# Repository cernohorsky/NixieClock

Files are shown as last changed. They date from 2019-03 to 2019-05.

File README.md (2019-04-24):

# NixieClock Arduino Mega shield
NixieClock PCB for nixie tubes ZM1080, ZM1082, Z570M, Z5700M. High voltage DC-DC convertor. RTC for time synchronization.

<b>Ideas:</b><br>
Different DCDC convertor parts values<br>
Different buttons position<br>

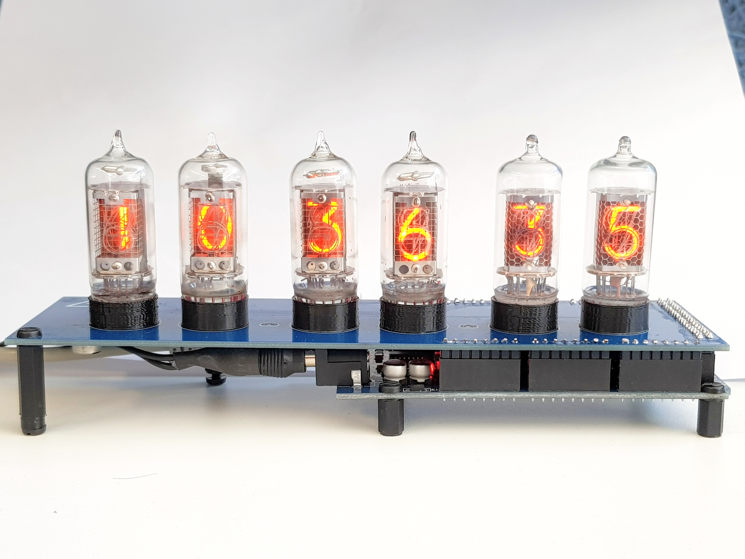
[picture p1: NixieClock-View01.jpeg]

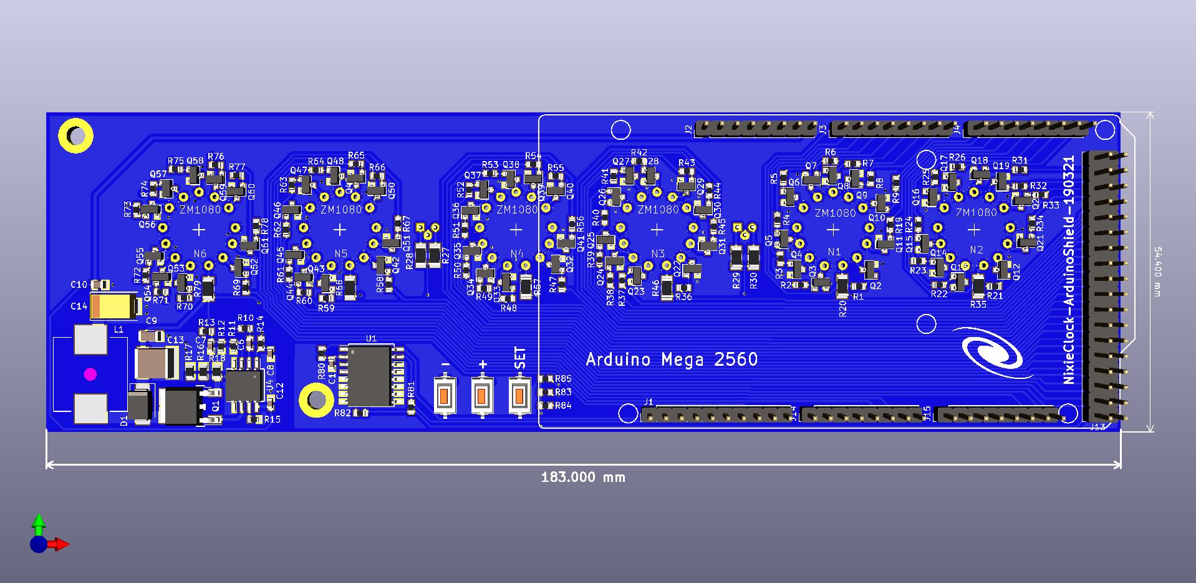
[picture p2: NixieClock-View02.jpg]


#ZM1080, #ZM1082, #Z570M, #Z5700M #Arduino, #Mega2560 #nixieclock, #nixie

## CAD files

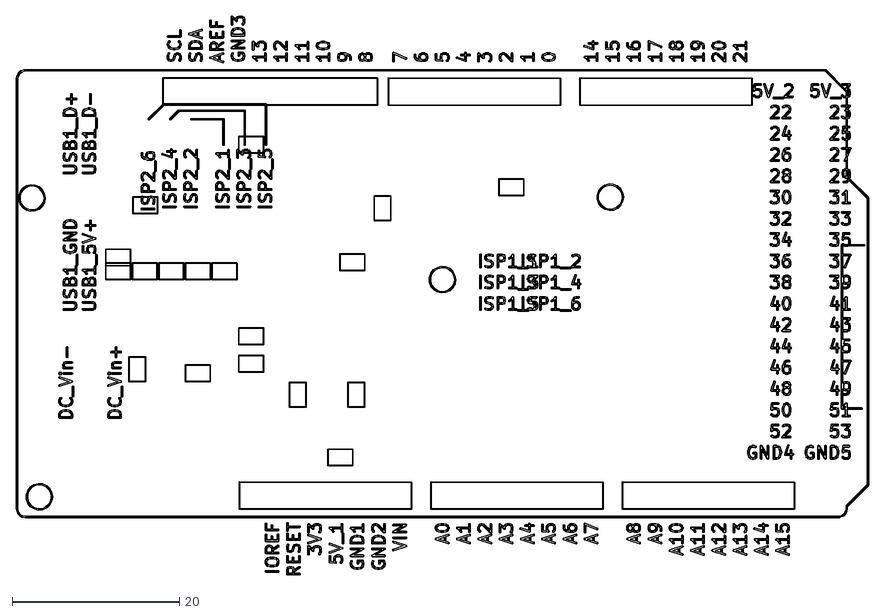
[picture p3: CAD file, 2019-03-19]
inpiration/ArduinoMega2560-Dimensions/MEGA2560_Rev3e-Dwgs.User.dxf
101.8 x 66.8

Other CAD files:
inpiration/ArduinoMega2560-Dimensions/MEGA2560_Rev3e-F.SilkS.dxf

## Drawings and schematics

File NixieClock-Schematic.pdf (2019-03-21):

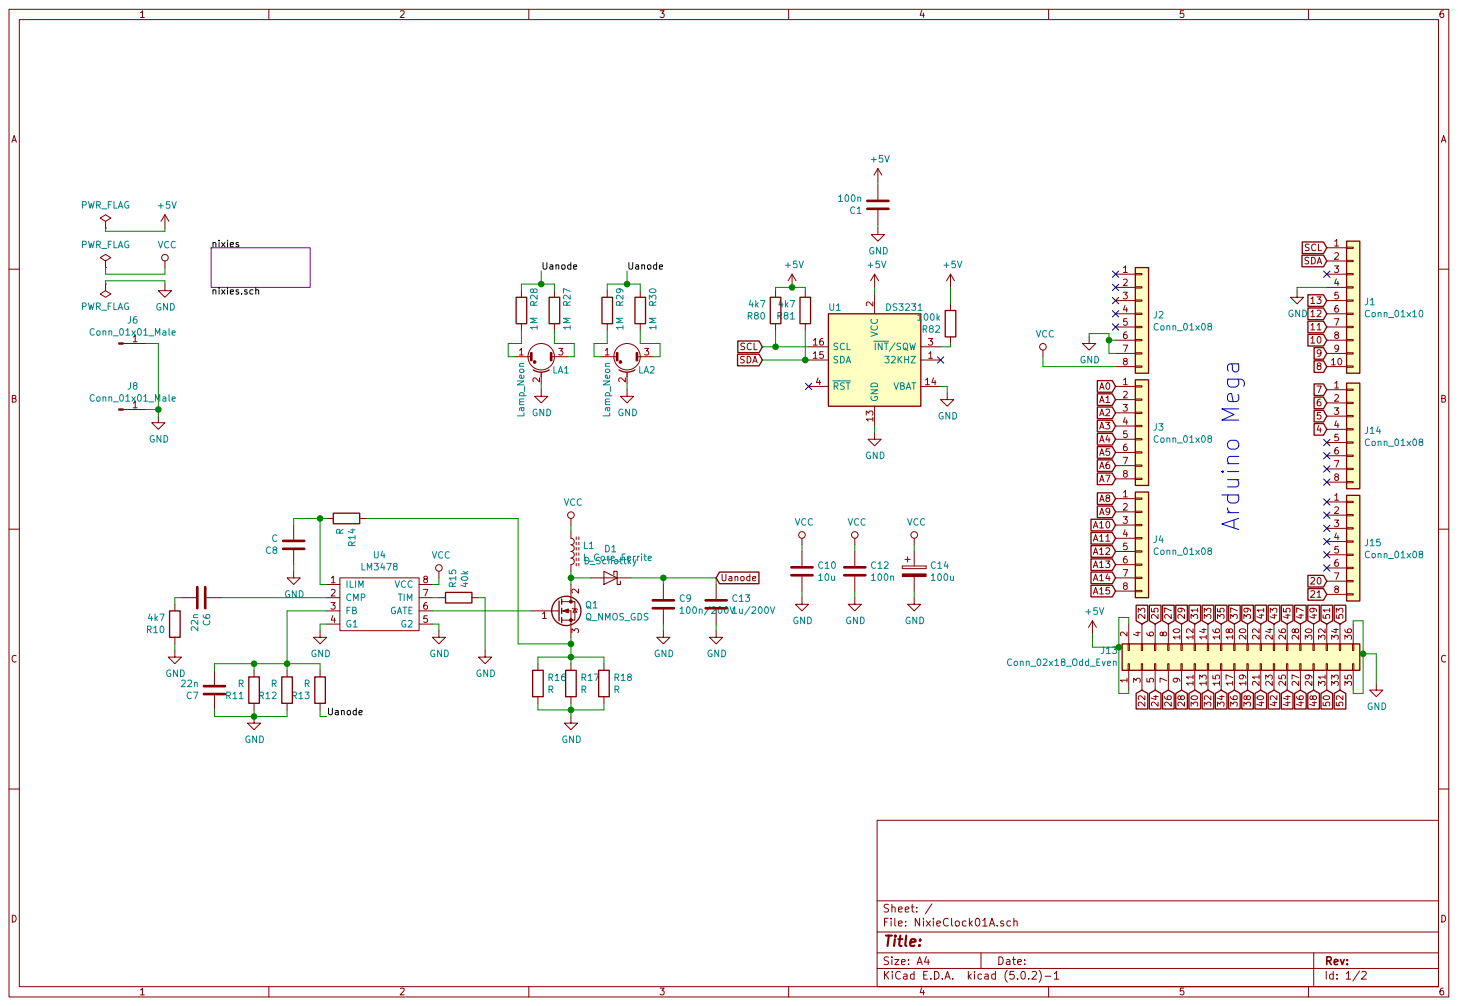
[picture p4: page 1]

Id: 1/2 Title: File: NixieClock01A.sch Sheet: /

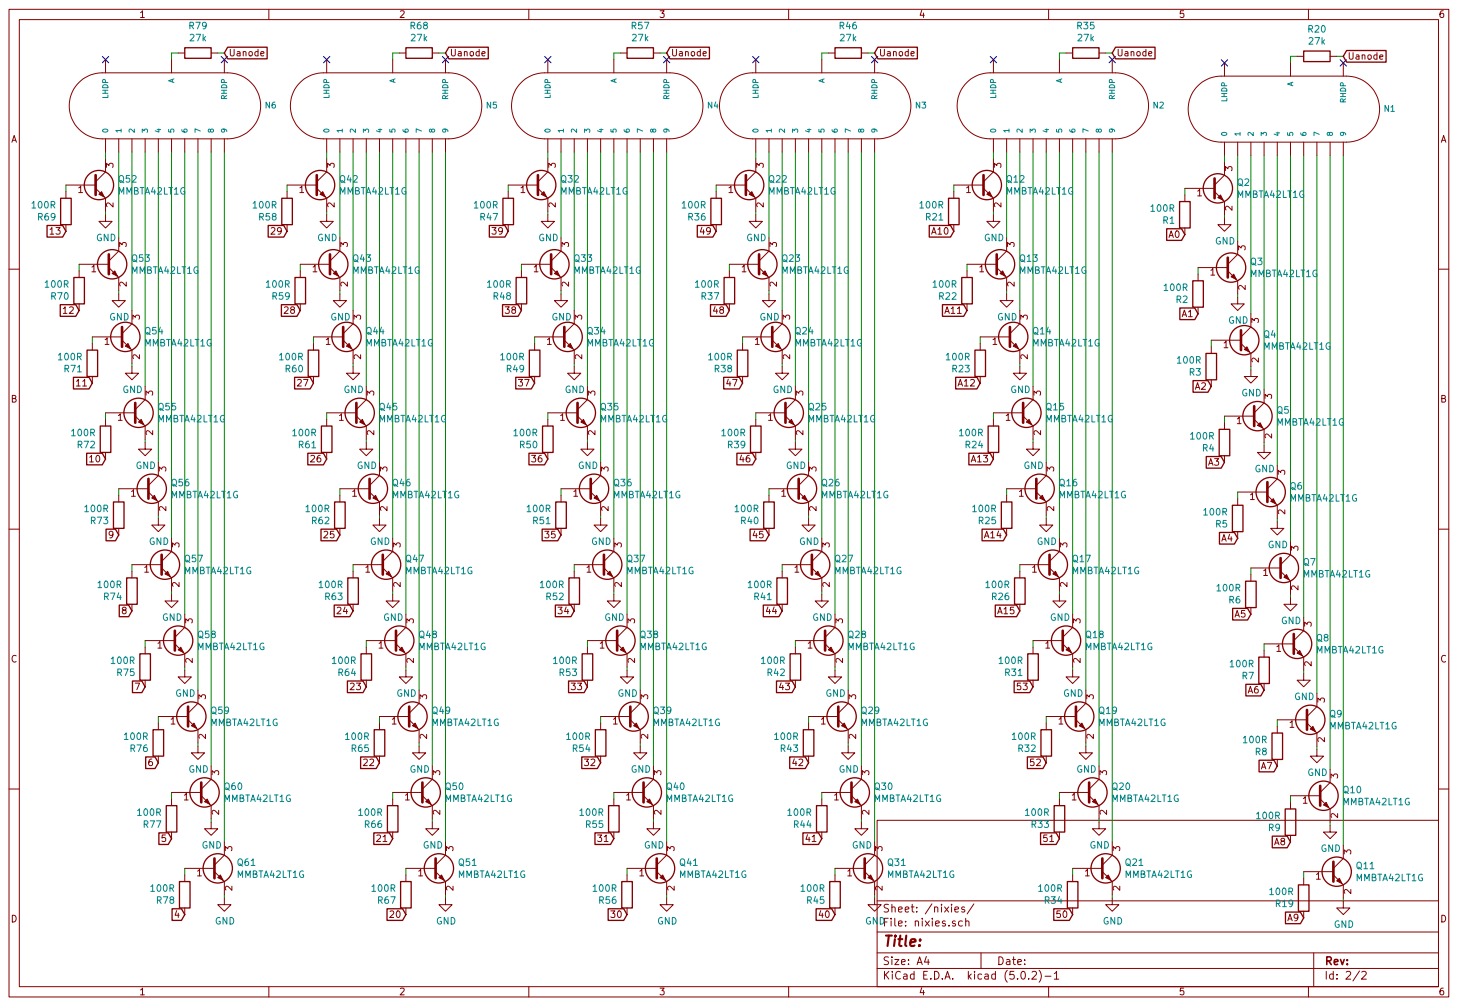
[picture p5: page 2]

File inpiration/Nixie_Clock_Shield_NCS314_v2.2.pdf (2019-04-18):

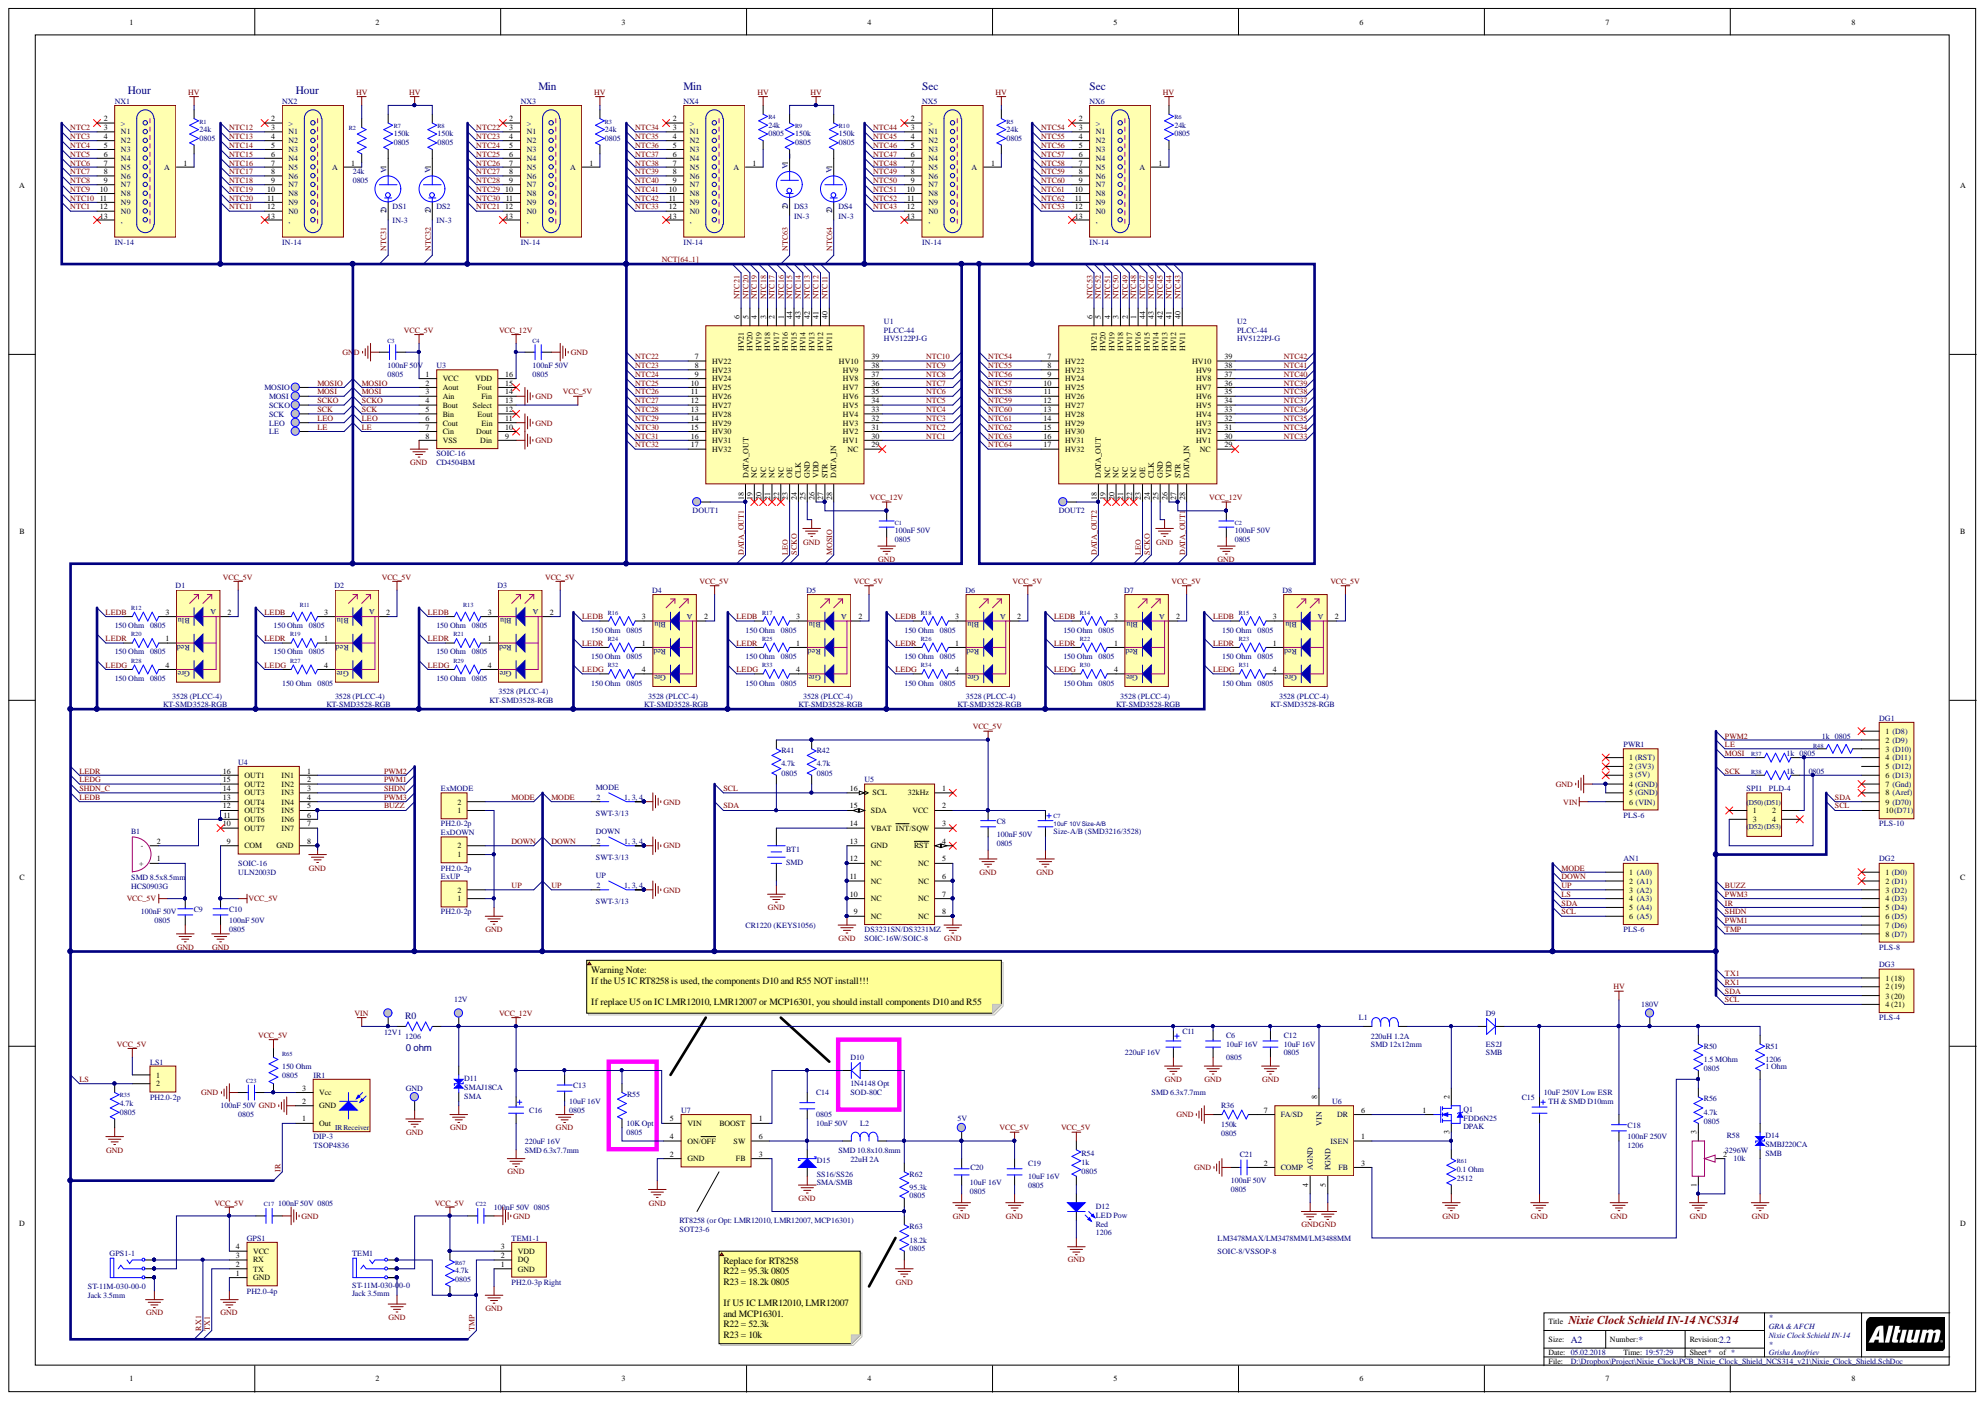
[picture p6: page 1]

VCC_5V VCC_12V

NTC9 | NTC55 | HV23 8 | NTC41

NTC1 | NTC63 | HV31 16 | NTC33

Warning Note:
If the U5 IC RT8258 is used, the components D10 and R55 NOT install!!!

If replace U5 on IC LMR12010, LMR12007 or MCP16301, you should install components D10 and R55

Nixie Clock Schield IN-14 NCS314 Title | * GRA & AFCH Nixie Clock Schield IN-14 * Grisha Anofriev

Size: A2 | Number: * | Revision: 2.2

Date: 05.02.2018 Time: 19:57:29 | | Sheet * of *

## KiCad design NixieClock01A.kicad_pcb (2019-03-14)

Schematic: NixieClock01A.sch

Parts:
C1, C2, C3, C5, C11, C12, C15, C17, C18, C19, C20, C21, C22, C23, C24, C27, C28, C31, C32: 100n; C_0603_1608Metric
C4, C16: TPSC107K010R0075; CP_EIA-6032-28_Kemet-C
C6, C7: 22n; C_0603_1608Metric
C8: C; C_0603_1608Metric
C9: 100n/200V; C_1206_3216Metric
C10, C26: 10u; C_0805_2012Metric
C13: 1u/200V; C_2220_5650Metric
C14: 100u; CP_EIA-7343-31_Kemet-D
C30: 1u; C_0603_1608Metric
D1: D_Schottky; D_SMB
D2, D3, D4, D5, D6, D7: WS2812B; LED_WS2812B_PLCC4_5.0x5.0mm_P3.2mm
D8: D_TVS; D_SMC
F1: Fuse; Fuse_1206_3216Metric
J1: Conn_01x06_Male; PinHeader_1x06_P2.54mm_Vertical
J2, J3: Conn_02x16_Odd_Even; PinSocket_2x16_P2.54mm_Vertical
J4: USB_B_Micro; USB_Micro-B_Molex-105017-0001
J5, J6, J7, J8, J9, J10, J11, J12: Conn_01x01_Male; MountingHole_3.2mm_M3_DIN965_Pad
J13: Conn_01x02_Male; PinHeader_1x02_P2.54mm_Vertical
J14: Conn_01x04_Male; PinSocket_1x04_P2.54mm_Vertical
L1: L_Core_Ferrite; L_Wuerth_WE-PD-Typ-LS_Handsoldering
LA1, LA2: Lamp_Neon; TO-92
N1, N2, N3, N4, N5, N6: ZM1080
Q1: Q_NMOS_GDS; TO-252-2
R1, R11, R12, R13, R14, R19, R20: R; R_0603_1608Metric
R2, R3, R4, R5, R6: 12k; R_0603_1608Metric
R7: 330k; R_0603_1608Metric
R8: 100k; R_0603_1608Metric
R9: 470R; R_0603_1608Metric
R10: 4k7; R_0603_1608Metric
R15: 40k; R_0603_1608Metric
R16, R17, R18: R; R_0805_2012Metric
R21, R22, R23, R24, R25, R26: 27k; R_1206_3216Metric
R27, R28, R29, R30: 1M; R_1206_3216Metric
R31, R32: 4K7; R_0603_1608Metric
U1, U5, U8, U11, U12, U13: 74141; DIP-16_W7.62mm
U2, U6, U7: PCF8574; SOIC-16W_5.3x10.2mm_P1.27mm
U3: ESP-12E
U4: LM3478; SO-8_5.3x6.2mm_P1.27mm
U9: TC1262-33; SOT-223

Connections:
+3V3: C2.1, C4.1, C5.1, C18.1, C21.1, C30.1, J1.2, J2.4, J3.4, J14.2, R1.1, R2.2, R3.2, R4.2, R5.2, R19.1, R20.1, R31.2, R32.2, U2.16, U3.8, U6.16, U7.16, U9.3
+5V: C1.1, C10.1, C11.1, C12.1, C14.1, C15.1, C16.1, C17.1, C19.1, C20.1, C22.1, C23.1, C24.1, C26.1, C27.1, C28.1, C31.1, C32.1, D2.1, D3.1, D4.1, D5.1, D6.1, D7.1, D8.1, F1.1, J2.2, J3.2, L1.1, U1.5, U4.8, U5.5, U8.5, U9.1, U11.5, U12.5, U13.5
/A1: J2.10, J3.10, U1.3, U2.4
/A2: J2.9, J3.9, U1.6, U2.5
/A3: J2.12, J3.12, U1.7, U2.6
/A4: J2.11, J3.11, U1.4, U2.7
/ADC: R7.2, R8.1, U3.2
/ADC-IN: J13.2, R7.1
/B1: J2.14, J3.14, U2.9, U5.3
/B2: J2.13, J3.13, U2.10, U5.6
/B3: J2.16, J3.16, U2.11, U5.7
/B4: J2.15, J3.15, U2.12, U5.4
/C1: J2.18, J3.18, U6.4, U8.3
/C2: J2.17, J3.17, U6.5, U8.6
/C3: J2.20, J3.20, U6.6, U8.7
/C4: J2.19, J3.19, U6.7, U8.4
/D1: J2.22, J3.22, U6.9, U11.3
/D2: J2.21, J3.21, U6.10, U11.6
/D3: J2.24, J3.24, U6.11, U11.7
/D4: J2.23, J3.23, U6.12, U11.4
/E1: J2.26, J3.26, U7.4, U12.3
/E2: J2.25, J3.25, U7.5, U12.6
/E3: J2.28, J3.28, U7.6, U12.7
/E4: J2.27, J3.27, U7.7, U12.4
/EN: R4.1, U3.3
/F1: J2.30, J3.30, U7.9, U13.3
/F2: J2.29, J3.29, U7.10, U13.6
/F3: J2.32, J3.32, U7.11, U13.7
/F4: J2.31, J3.31, U7.12, U13.4
/GPIO0: J1.5, R2.1, U3.18
/GPIO2: R3.1, U3.17
/GPIO15: R6.1, U3.16
/NeoPix: D2.4, J2.8, J3.8, U3.7
/RST: C3.1, J1.6, R5.1, R9.1, U3.1
/RX: J1.4, U3.21
/SCL: J14.3, R31.1, U2.14, U3.20, U6.14, U7.14
/SDA: J14.4, R32.1, U2.15, U3.19, U6.15, U7.15
/TX: J1.3, U3.22
/Uanode: C9.1, C13.1, D1.1, J2.1, J3.1, R13.1, R21.1, R22.1, R23.1, R24.1, R25.1, R26.1, R27.2, R28.2, R29.2, R30.2
GND: C1.2, C2.2, C3.2, C4.2, C5.2, C7.1, C8.1, C9.2, C10.2, C11.2, C12.2, C13.2, C14.2, C15.2, C16.2, C17.2, C18.2, C19.2, C20.2, C21.2, C22.2, C23.2, C24.2, C26.2, C27.2, C28.2, C30.2, C31.2, C32.2, D2.3, D3.3, D4.3, D5.3, D6.3, D7.3, D8.2, J1.1, J2.3, J2.5, J2.6, J2.7, J3.3, J3.5, J3.6, J3.7, J4.5, J4.6, J5.1, J6.1, J7.1, J8.1, J9.1, J10.1, J11.1, J12.1, J13.1, J14.1, LA1.2, LA2.2, R6.2, R8.2, R10.1, R11.1, R12.1, R15.2, R16.2, R17.2, R18.2, U1.12, U2.2, U2.3, U2.8, U3.15, U4.4, U4.5, U5.12, U6.1, U6.3, U6.8, U7.1, U7.2, U7.8, U8.12, U9.2, U9.4, U11.12, U12.12, U13.12
unnamed: C6.1, U4.2
unnamed: C6.2, R10.2
unnamed: C7.2, R11.2, R12.2, R13.2, U4.3
unnamed: C8.2, R14.2, U4.1
unnamed: D1.2, L1.2, Q1.2
unnamed: D2.2, D3.4
unnamed: D3.2, D4.4
unnamed: D4.2, D5.4
unnamed: D5.2, D6.4
unnamed: D6.2, D7.4
unnamed: F1.2, J4.1
unnamed: LA1.1, R28.1
unnamed: LA1.3, R27.1
unnamed: LA2.1, R29.1
unnamed: LA2.3, R30.1
unnamed: N1.1, U1.15
unnamed: N1.2, U1.8
unnamed: N1.3, U1.9
unnamed: N1.5, U1.13
unnamed: N1.6, U1.14
unnamed: N1.7, U1.11
unnamed: N1.8, U1.10
unnamed: N1.9, U1.1
unnamed: N1.11, U1.2
unnamed: N1.12, U1.16
unnamed: N1.13, R21.2
unnamed: N2.1, U5.15
unnamed: N2.2, U5.8
unnamed: N2.3, U5.9
unnamed: N2.5, U5.13
unnamed: N2.6, U5.14
unnamed: N2.7, U5.11
unnamed: N2.8, U5.10
unnamed: N2.9, U5.1
unnamed: N2.11, U5.2
unnamed: N2.12, U5.16
unnamed: N2.13, R22.2
unnamed: N3.1, U8.15
unnamed: N3.2, U8.8
unnamed: N3.3, U8.9
unnamed: N3.5, U8.13
unnamed: N3.6, U8.14
unnamed: N3.7, U8.11
unnamed: N3.8, U8.10
unnamed: N3.9, U8.1
unnamed: N3.11, U8.2
unnamed: N3.12, U8.16
unnamed: N3.13, R23.2
unnamed: N4.1, U11.15
unnamed: N4.2, U11.8
unnamed: N4.3, U11.9
unnamed: N4.5, U11.13
unnamed: N4.6, U11.14
unnamed: N4.7, U11.11
unnamed: N4.8, U11.10
unnamed: N4.9, U11.1
unnamed: N4.11, U11.2
unnamed: N4.12, U11.16
unnamed: N4.13, R24.2
unnamed: N5.1, U12.15
unnamed: N5.2, U12.8
unnamed: N5.3, U12.9
unnamed: N5.5, U12.13
unnamed: N5.6, U12.14
unnamed: N5.7, U12.11
unnamed: N5.8, U12.10
unnamed: N5.9, U12.1
unnamed: N5.11, U12.2
unnamed: N5.12, U12.16
unnamed: N5.13, R25.2
unnamed: N6.1, U13.15
unnamed: N6.2, U13.8
unnamed: N6.3, U13.9
unnamed: N6.5, U13.13
unnamed: N6.6, U13.14
unnamed: N6.7, U13.11
unnamed: N6.8, U13.10
unnamed: N6.9, U13.1
unnamed: N6.11, U13.2
unnamed: N6.12, U13.16
unnamed: N6.13, R26.2
unnamed: Q1.1, U4.6
unnamed: Q1.3, R14.1, R16.1, R17.1, R18.1
unnamed: R1.2, U2.1
unnamed: R9.2, U3.4
unnamed: R15.1, U4.7
unnamed: R19.2, U6.2
unnamed: R20.2, U7.3

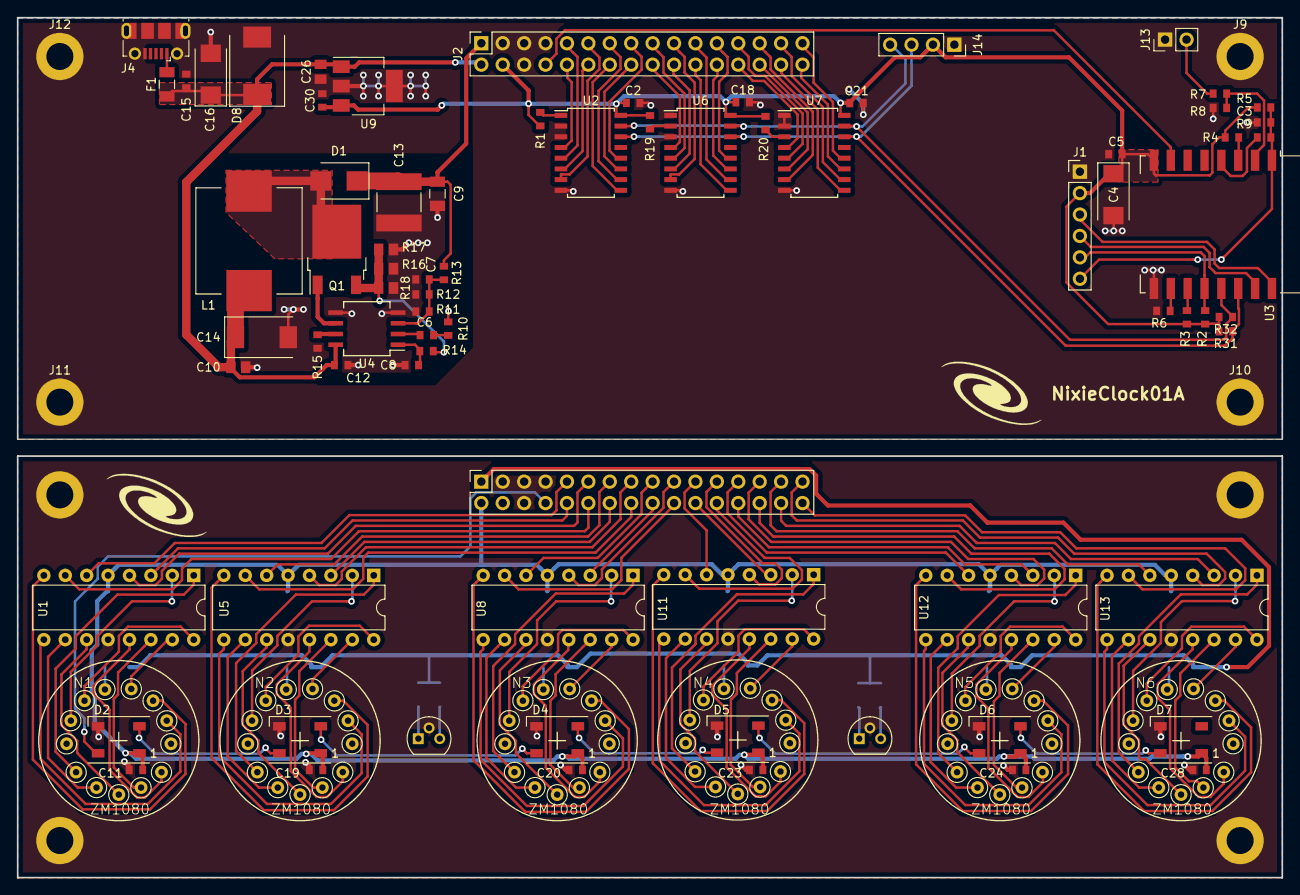
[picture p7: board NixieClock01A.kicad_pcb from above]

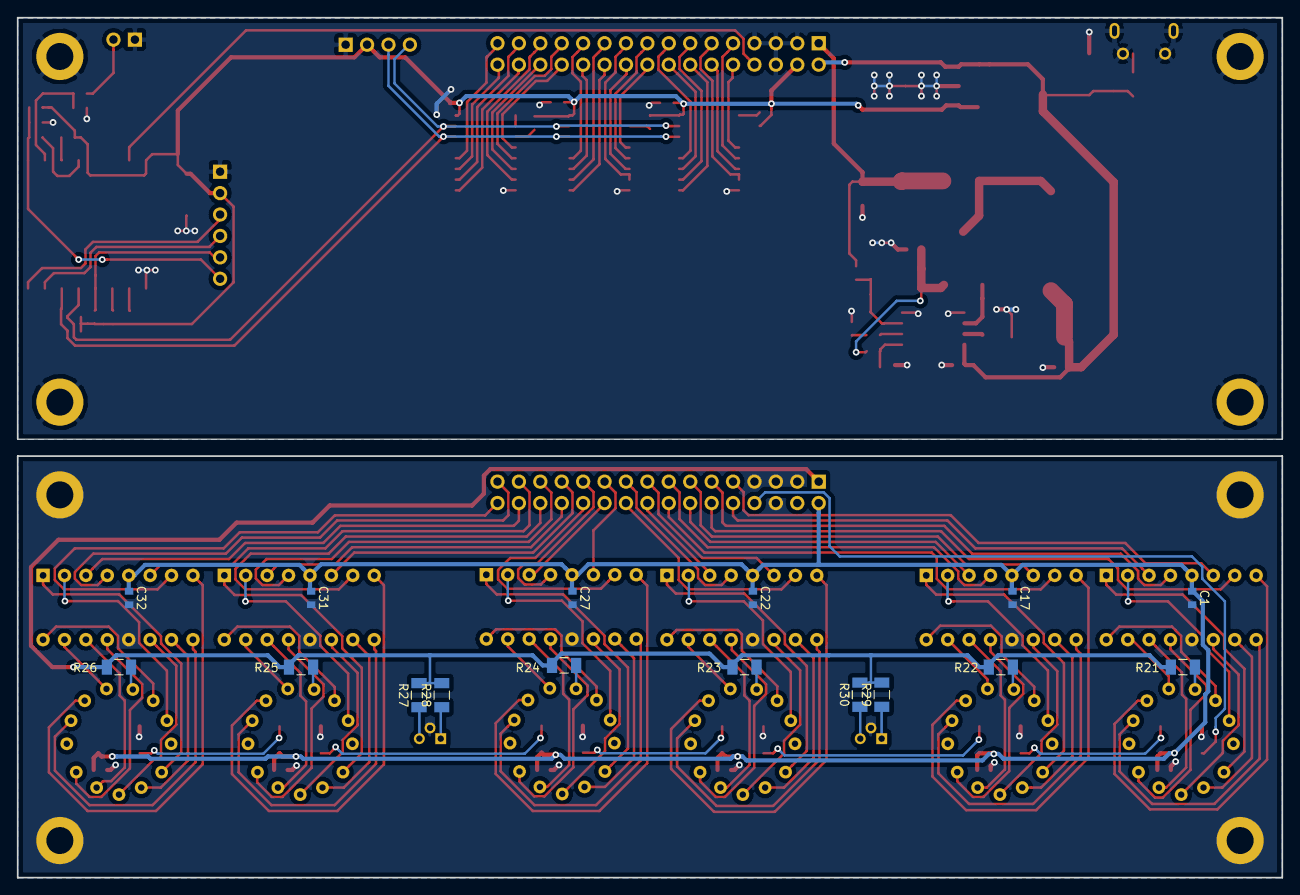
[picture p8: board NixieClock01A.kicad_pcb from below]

Board: 2 copper layers, 150.0 x 102.0 mm, 107 parts (16 on the bottom side), 128 nets.

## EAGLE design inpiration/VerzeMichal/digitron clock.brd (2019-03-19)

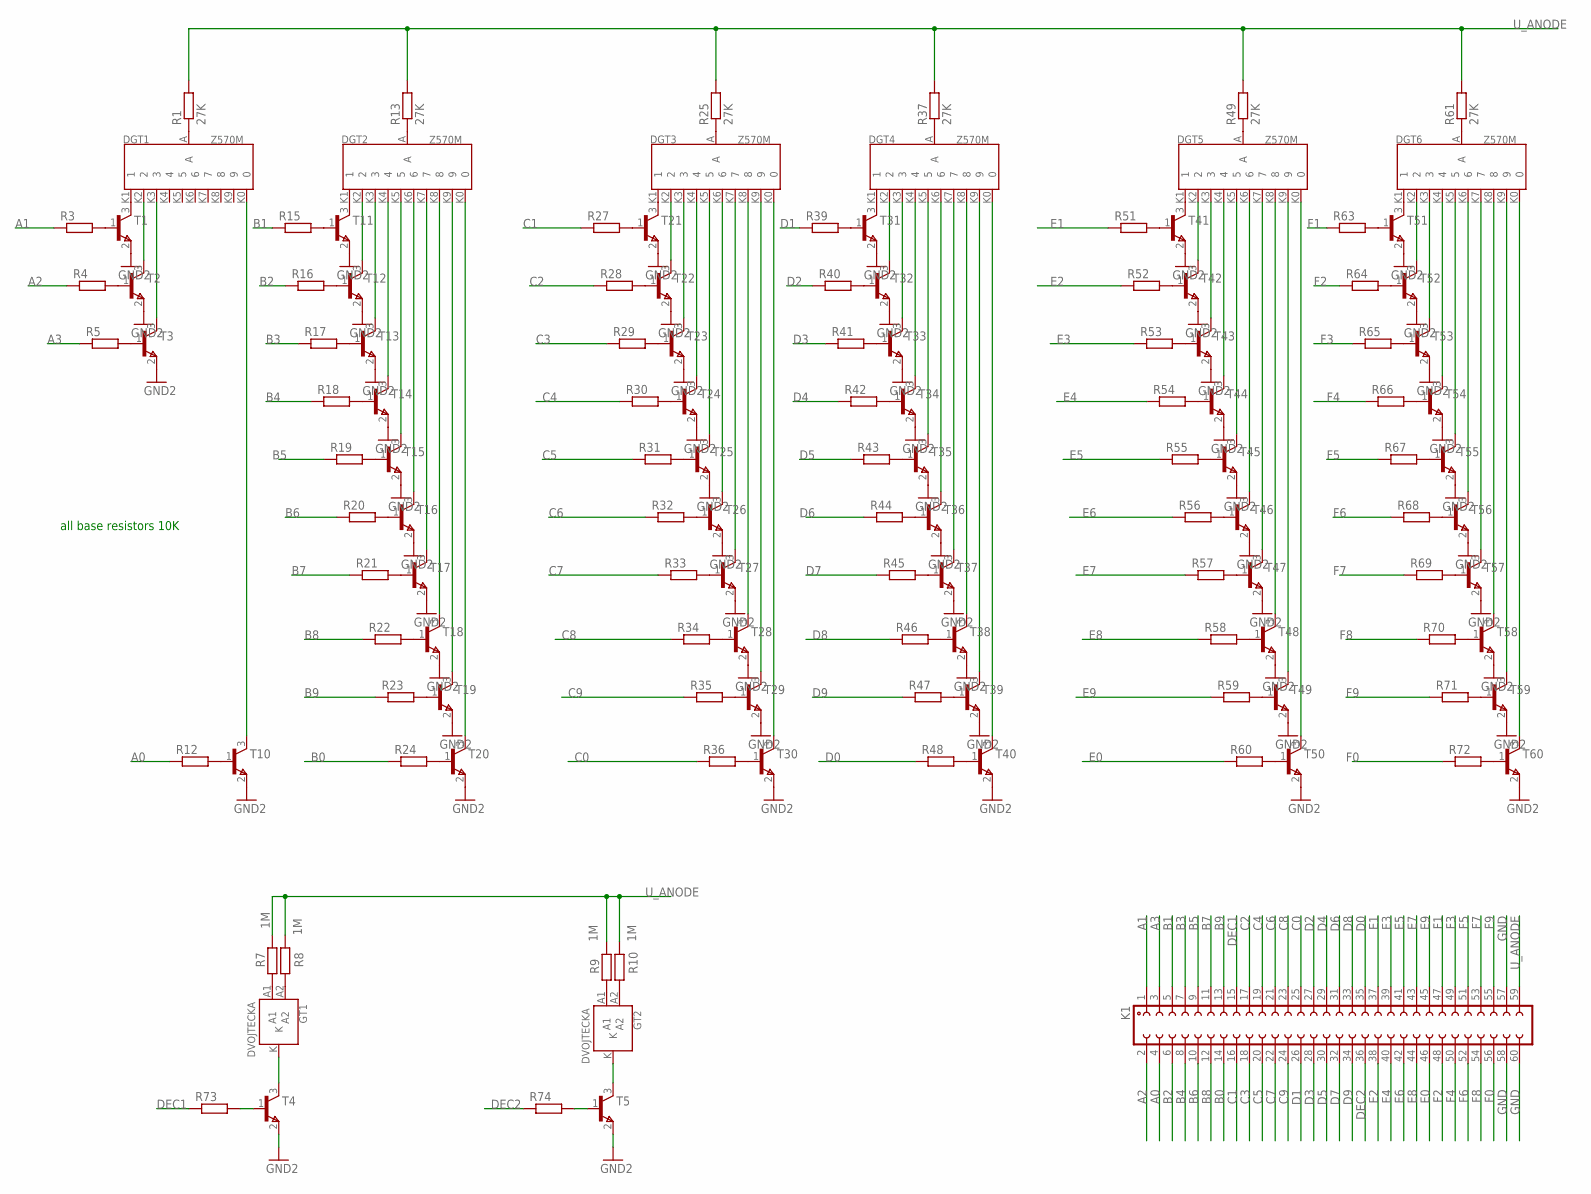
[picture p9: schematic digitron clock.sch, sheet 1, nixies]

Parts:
DGT1, DGT2, DGT3, DGT4, DGT5, DGT6: Z570M
GT1, GT2: DVOJTECKA
K1: K_60PIN_F; FE30-2
R1, R13, R25, R37, R49, R61: 27K; 1206
R3, R4, R5, R12, R15, R16, R17, R18, R19, R20, R21, R22, R23, R24, R27, R28, R29, R30, R31, R32, R33, R34, R35, R36, R39, R40, R41, R42, R43, R44, R45, R46, R47, R48, R51, R52, R53, R54, R55, R56, R57, R58, R59, R60, R63, R64, R65, R66, R67, R68, R69, R70, R71, R72, R73, R74: R_SMD0603; 0603
R7, R8, R9, R10: 1M; 1206
T1, T2, T3, T4, T5, T10, T11, T12, T13, T14, T15, T16, T17, T18, T19, T20, T21, T22, T23, T24, T25, T26, T27, T28, T29, T30, T31, T32, T33, T34, T35, T36, T37, T38, T39, T40, T41, T42, T43, T44, T45, T46, T47, T48, T49, T50, T51, T52, T53, T54, T55, T56, T57, T58, T59, T60: BC848B; SOT-23

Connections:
A0: K1.4, R12.1
A1: K1.1, R3.1
A2: K1.2, R4.1
A3: K1.3, R5.1
B0: K1.14, R24.1
B1: K1.5, R15.1
B2: K1.6, R16.1
B3: K1.7, R17.1
B4: K1.8, R18.1
B5: K1.9, R19.1
B6: K1.10, R20.1
B7: K1.11, R21.1
B8: K1.12, R22.1
B9: K1.13, R23.1
C0: K1.25, R36.1
C1: K1.16, R27.1
C2: K1.17, R28.1
C3: K1.18, R29.1
C4: K1.19, R30.1
C5: K1.20, R31.1
C6: K1.21, R32.1
C7: K1.22, R33.1
C8: K1.23, R34.1
C9: K1.24, R35.1
D0: K1.35, R48.1
D1: K1.26, R39.1
D2: K1.27, R40.1
D3: K1.28, R41.1
D4: K1.29, R42.1
D5: K1.30, R43.1
D6: K1.31, R44.1
D7: K1.32, R45.1
D8: K1.33, R46.1
D9: K1.34, R47.1
DEC1: K1.15, R73.1
DEC2: K1.36, R74.1
E0: K1.46, R60.1
E1: K1.37, R51.1
E2: K1.38, R52.1
E3: K1.39, R53.1
E4: K1.40, R54.1
E5: K1.41, R55.1
E6: K1.42, R56.1
E7: K1.43, R57.1
E8: K1.44, R58.1
E9: K1.45, R59.1
F0: K1.56, R72.1
F1: K1.47, R63.1
F2: K1.48, R64.1
F3: K1.49, R65.1
F4: K1.50, R66.1
F5: K1.51, R67.1
F6: K1.52, R68.1
F7: K1.53, R69.1
F8: K1.54, R70.1
F9: K1.55, R71.1
GND: K1.57, K1.58, K1.60, T1.2 (E), T2.2 (E), T3.2 (E), T4.2 (E), T5.2 (E), T10.2 (E), T11.2 (E), T12.2 (E), T13.2 (E), T14.2 (E), T15.2 (E), T16.2 (E), T17.2 (E), T18.2 (E), T19.2 (E), T20.2 (E), T21.2 (E), T22.2 (E), T23.2 (E), T24.2 (E), T25.2 (E), T26.2 (E), T27.2 (E), T28.2 (E), T29.2 (E), T30.2 (E), T31.2 (E), T32.2 (E), T33.2 (E), T34.2 (E), T35.2 (E), T36.2 (E), T37.2 (E), T38.2 (E), T39.2 (E), T40.2 (E), T41.2 (E), T42.2 (E), T43.2 (E), T44.2 (E), T45.2 (E), T46.2 (E), T47.2 (E), T48.2 (E), T49.2 (E), T50.2 (E), T51.2 (E), T52.2 (E), T53.2 (E), T54.2 (E), T55.2 (E), T56.2 (E), T57.2 (E), T58.2 (E), T59.2 (E), T60.2 (E)
unnamed: DGT1.K1 (1), T1.3 (C)
unnamed: DGT1.K2 (2), T2.3 (C)
unnamed: DGT1.K3 (3), T3.3 (C)
unnamed: GT1.A1, R7.1
unnamed: GT1.A2, R8.1
unnamed: GT2.A1, R9.1
unnamed: GT1.K, T4.3 (C)
unnamed: GT2.K, T5.3 (C)
unnamed: R74.2, T5.1 (B)
unnamed: DGT1.K0 (0), T10.3 (C)
unnamed: GT2.A2, R10.1
unnamed: DGT1.A, R1.1
unnamed: R3.2, T1.1 (B)
unnamed: R4.2, T2.1 (B)
unnamed: R5.2, T3.1 (B)
unnamed: R73.2, T4.1 (B)
unnamed: R12.2, T10.1 (B)
unnamed: DGT2.K1 (1), T11.3 (C)
unnamed: DGT2.K2 (2), T12.3 (C)
unnamed: DGT2.K3 (3), T13.3 (C)
unnamed: DGT2.K4 (4), T14.3 (C)
unnamed: DGT2.K5 (5), T15.3 (C)
unnamed: DGT2.K6 (6), T16.3 (C)
unnamed: DGT2.K7 (7), T17.3 (C)
unnamed: DGT2.K8 (8), T18.3 (C)
unnamed: DGT2.K9 (9), T19.3 (C)
unnamed: DGT2.K0 (0), T20.3 (C)
unnamed: DGT2.A, R13.1
unnamed: R15.2, T11.1 (B)
unnamed: R16.2, T12.1 (B)
unnamed: R17.2, T13.1 (B)
unnamed: R18.2, T14.1 (B)
unnamed: R19.2, T15.1 (B)
unnamed: R20.2, T16.1 (B)
unnamed: R21.2, T17.1 (B)
unnamed: R22.2, T18.1 (B)
unnamed: R23.2, T19.1 (B)
unnamed: R24.2, T20.1 (B)
unnamed: DGT3.K1 (1), T21.3 (C)
unnamed: DGT3.K2 (2), T22.3 (C)
unnamed: DGT3.K3 (3), T23.3 (C)
unnamed: DGT3.K4 (4), T24.3 (C)
unnamed: DGT3.K5 (5), T25.3 (C)
unnamed: DGT3.K6 (6), T26.3 (C)
unnamed: DGT3.K7 (7), T27.3 (C)
unnamed: DGT3.K8 (8), T28.3 (C)
unnamed: DGT3.K9 (9), T29.3 (C)
unnamed: DGT3.K0 (0), T30.3 (C)
unnamed: DGT3.A, R25.1
unnamed: R27.2, T21.1 (B)
unnamed: R28.2, T22.1 (B)
unnamed: R29.2, T23.1 (B)
unnamed: R30.2, T24.1 (B)
unnamed: R31.2, T25.1 (B)
unnamed: R32.2, T26.1 (B)
unnamed: R33.2, T27.1 (B)
unnamed: R34.2, T28.1 (B)
unnamed: R35.2, T29.1 (B)
unnamed: R36.2, T30.1 (B)
unnamed: DGT4.K1 (1), T31.3 (C)
unnamed: DGT4.K2 (2), T32.3 (C)
unnamed: DGT4.K3 (3), T33.3 (C)
unnamed: DGT4.K4 (4), T34.3 (C)
unnamed: DGT4.K5 (5), T35.3 (C)
unnamed: DGT4.K6 (6), T36.3 (C)
unnamed: DGT4.K7 (7), T37.3 (C)
unnamed: DGT4.K8 (8), T38.3 (C)
unnamed: DGT4.K9 (9), T39.3 (C)
unnamed: DGT4.K0 (0), T40.3 (C)
unnamed: DGT4.A, R37.1
unnamed: R39.2, T31.1 (B)
unnamed: R40.2, T32.1 (B)
unnamed: R41.2, T33.1 (B)
unnamed: R42.2, T34.1 (B)
unnamed: R43.2, T35.1 (B)
unnamed: R44.2, T36.1 (B)
unnamed: R45.2, T37.1 (B)
unnamed: R46.2, T38.1 (B)
unnamed: R47.2, T39.1 (B)
unnamed: R48.2, T40.1 (B)
unnamed: DGT5.K1 (1), T41.3 (C)
unnamed: DGT5.K2 (2), T42.3 (C)
unnamed: DGT5.K3 (3), T43.3 (C)
unnamed: DGT5.K4 (4), T44.3 (C)
unnamed: DGT5.K5 (5), T45.3 (C)
unnamed: DGT5.K6 (6), T46.3 (C)
unnamed: DGT5.K7 (7), T47.3 (C)
unnamed: DGT5.K8 (8), T48.3 (C)
unnamed: DGT5.K9 (9), T49.3 (C)
unnamed: DGT5.K0 (0), T50.3 (C)
unnamed: DGT5.A, R49.1
unnamed: R51.2, T41.1 (B)
unnamed: R52.2, T42.1 (B)
unnamed: R53.2, T43.1 (B)
unnamed: R54.2, T44.1 (B)
unnamed: R55.2, T45.1 (B)
unnamed: R56.2, T46.1 (B)
unnamed: R57.2, T47.1 (B)
unnamed: R58.2, T48.1 (B)
unnamed: R59.2, T49.1 (B)
unnamed: R60.2, T50.1 (B)
unnamed: DGT6.K1 (1), T51.3 (C)
unnamed: DGT6.K2 (2), T52.3 (C)
unnamed: DGT6.K3 (3), T53.3 (C)
unnamed: DGT6.K4 (4), T54.3 (C)
unnamed: DGT6.K5 (5), T55.3 (C)
unnamed: DGT6.K6 (6), T56.3 (C)
unnamed: DGT6.K7 (7), T57.3 (C)
unnamed: DGT6.K8 (8), T58.3 (C)
unnamed: DGT6.K9 (9), T59.3 (C)
unnamed: DGT6.K0 (0), T60.3 (C)
unnamed: DGT6.A, R61.1
unnamed: R63.2, T51.1 (B)
unnamed: R64.2, T52.1 (B)
unnamed: R65.2, T53.1 (B)
unnamed: R66.2, T54.1 (B)
unnamed: R67.2, T55.1 (B)
unnamed: R68.2, T56.1 (B)
unnamed: R69.2, T57.1 (B)
unnamed: R70.2, T58.1 (B)
unnamed: R71.2, T59.1 (B)
unnamed: R72.2, T60.1 (B)
U_ANODE: K1.59, R1.2, R7.2, R8.2, R9.2, R10.2, R13.2, R25.2, R37.2, R49.2, R61.2

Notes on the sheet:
all base resistors 10K

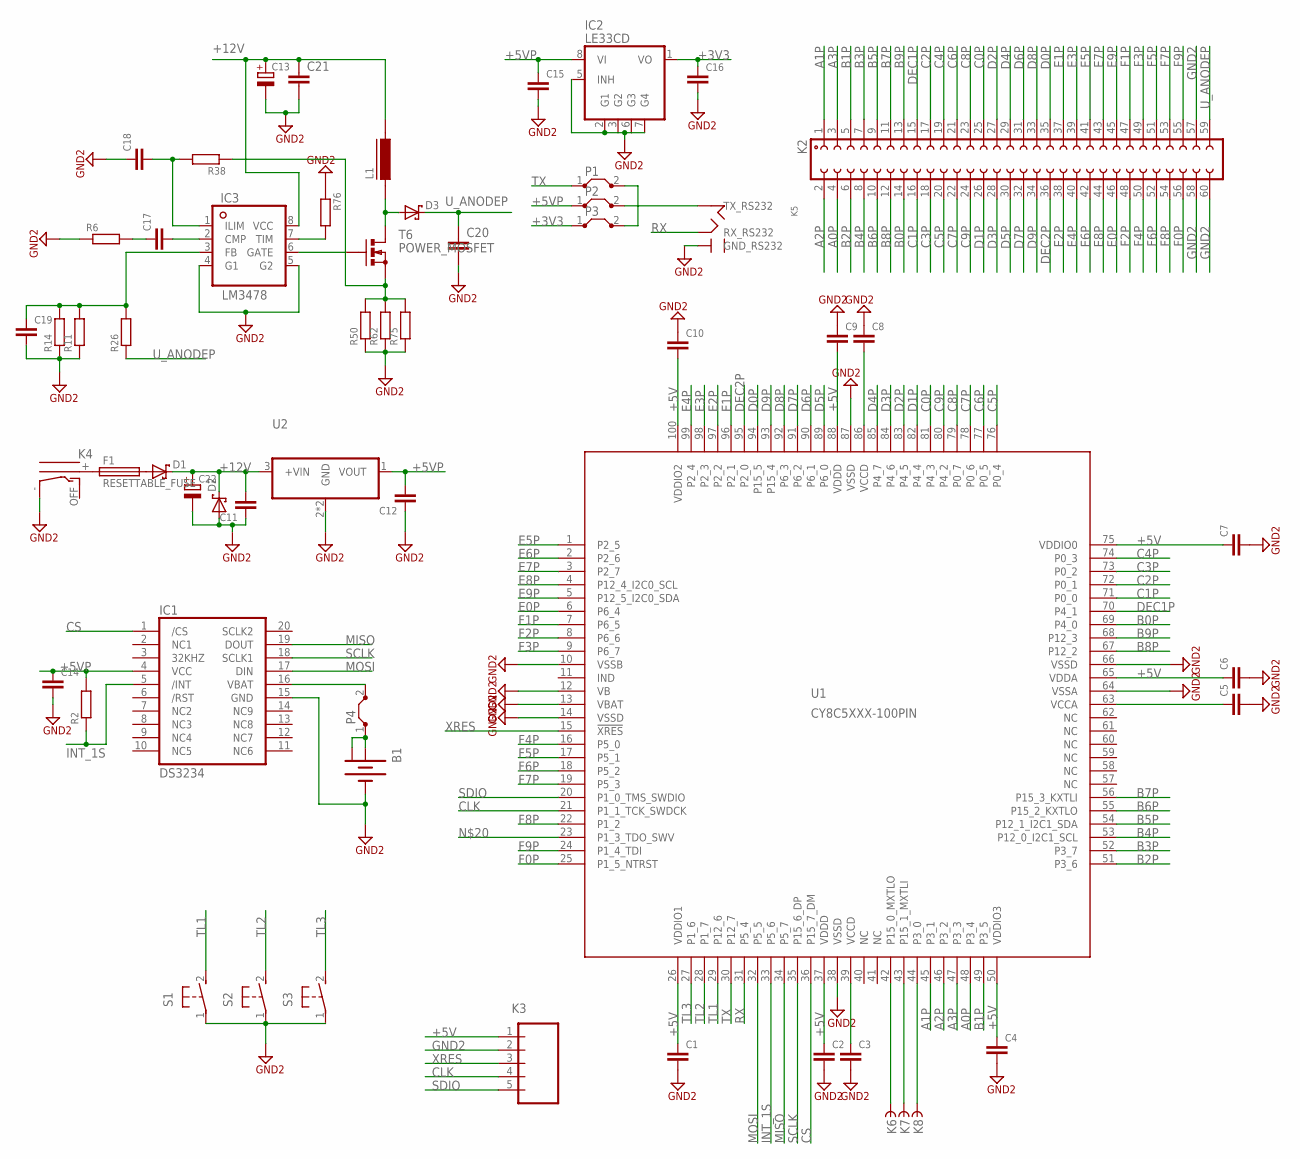
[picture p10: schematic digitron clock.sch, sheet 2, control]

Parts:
B1: BATERIE3VX; CR2430X
C1, C2, C3, C4, C5, C6, C7, C8, C9, C10, C11, C12, C14, C15, C16, C17, C18, C19, C21: C_SMD0603; 0603
C13, C22: C_TANTALC-D; C-D
C20: C_SMD2220; 2220
D1, D2, D3: 10BQ040; D-SMB
F1: RESETTABLE_FUSE; SMD1812
IC1: DS3234; SO20L
IC2: LE33CD; SO8
IC3: LM3478; SO8
K2: K_60PIN_F; FE30-2
K3: MA5-1
K4: DC_CONNECTOR_RAPC712; DC_CONECTOR_RAPC712
K5: JACK
K6, K7, K8: FUTURE_PAD
L1: DR127
P1, P2, P3, P4: K_SMD_PROPOJKA; JUMP-2
R2, R6, R11, R14, R26, R38, R76: R_SMD0603; 0603
R50, R62, R75: R_SMD0805; 0805
S1, S2, S3: 31-XX; B3F-31XX
T6: POWER_MOSFET; TO252
U1: CY8C5XXX-100PIN; TQFP-14X14-100
U2: 78XXSOT89; SOT89

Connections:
+3V3: C16.1, IC2.1 (VO), P3.1
+5V: C1.1, C2.1, C4.1, C6.1, C7.1, C9.2, C10.2, K3.1, U1.26 (VDDIO1), U1.37 (VDDD), U1.50 (VDDIO3), U1.65 (VDDA), U1.75 (VDDIO0), U1.88 (VDDD), U1.100 (VDDIO2)
+5VP: C12.2, C14.1, C15.1, IC1.4 (VCC), IC2.8 (VI), P2.1, R2.2, U2.1 (VOUT)
+12V: C11.2, C13.+, C21.1, C22.+, D1.K, D2.K, IC3.8 (VCC), L1.P$2 (2), U2.3 (+VIN)
A0P: K2.4, U1.48 (P3_4)
A1P: K2.1, U1.45 (P3_1)
A2P: K2.2, U1.46 (P3_2)
A3P: K2.3, U1.47 (P3_3)
B0P: K2.14, U1.69 (P4_0)
B1P: K2.5, U1.49 (P3_5)
B2P: K2.6, U1.51 (P3_6)
B3P: K2.7, U1.52 (P3_7)
B4P: K2.8, U1.53 (P12_0_I2C1_SCL)
B5P: K2.9, U1.54 (P12_1_I2C1_SDA)
B6P: K2.10, U1.55 (P15_2_KXTLO)
B7P: K2.11, U1.56 (P15_3_KXTLI)
B8P: K2.12, U1.67 (P12_2)
B9P: K2.13, U1.68 (P12_3)
C0P: K2.25, U1.81 (P4_3)
C1P: K2.16, U1.71 (P0_0)
C2P: K2.17, U1.72 (P0_1)
C3P: K2.18, U1.73 (P0_2)
C4P: K2.19, U1.74 (P0_3)
C5P: K2.20, U1.76 (P0_4)
C6P: K2.21, U1.77 (P0_5)
C7P: K2.22, U1.78 (P0_6)
C8P: K2.23, U1.79 (P0_7)
C9P: K2.24, U1.80 (P4_2)
CLK: K3.4, U1.21 (P1_1_TCK_SWDCK)
CS: IC1.1 (/CS), U1.36 (P15_7_DM)
D0P: K2.35, U1.94 (P15_5)
D1P: K2.26, U1.82 (P4_4)
D2P: K2.27, U1.83 (P4_5)
D3P: K2.28, U1.84 (P4_6)
D4P: K2.29, U1.85 (P4_7)
D5P: K2.30, U1.89 (P6_0)
D6P: K2.31, U1.90 (P6_1)
D7P: K2.32, U1.91 (P6_2)
D8P: K2.33, U1.92 (P6_3)
D9P: K2.34, U1.93 (P15_4)
DEC1P: K2.15, U1.70 (P4_1)
DEC2P: K2.36, U1.95 (P2_0)
E0P: K2.46, U1.6 (P6_4)
E1P: K2.37, U1.96 (P2_1)
E2P: K2.38, U1.97 (P2_2)
E3P: K2.39, U1.98 (P2_3)
E4P: K2.40, U1.99 (P2_4)
E5P: K2.41, U1.1 (P2_5)
E6P: K2.42, U1.2 (P2_6)
E7P: K2.43, U1.3 (P2_7)
E8P: K2.44, U1.4 (P12_4_I2C0_SCL)
E9P: K2.45, U1.5 (P12_5_I2C0_SDA)
F0P: K2.56, U1.25 (P1_5_NTRST)
F1P: K2.47, U1.7 (P6_5)
F2P: K2.48, U1.8 (P6_6)
F3P: K2.49, U1.9 (P6_7)
F4P: K2.50, U1.16 (P5_0)
F5P: K2.51, U1.17 (P5_1)
F6P: K2.52, U1.18 (P5_2)
F7P: K2.53, U1.19 (P5_3)
F8P: K2.54, U1.22 (P1_2)
F9P: K2.55, U1.24 (P1_4_TDI)
GND2: B1.-, C1.2, C2.2, C3.2, C4.2, C5.2, C6.2, C7.2, C8.1, C9.1, C10.1, C11.1, C12.1, C13.-, C14.2, C15.2, C16.2, C18.1, C19.2, C20.2, C21.2, C22.-, D2.A, IC1.15 (GND), IC2.2 (G1), IC2.3 (G2), IC2.5 (INH), IC2.6 (G3), IC2.7 (G4), IC3.4 (G1), IC3.5 (G2), K2.57, K2.58, K2.60, K3.2, K4.-, K5.GND_RS232, R6.1, R11.1, R14.1, R50.1, R62.1, R75.1, R76.1, S1.1, S2.1, S3.1, U1.10 (VSSB), U1.12 (VB), U1.13 (VBAT), U1.14 (VSSD), U1.38 (VSSD), U1.64 (VSSA), U1.66 (VSSD), U1.87 (VSSD), U2.2 (GND), U2.4 (GND)
INT_1S: IC1.5 (/INT), R2.1, U1.33 (P5_6)
MISO: IC1.19 (DOUT), U1.34 (P5_7)
MOSI: IC1.17 (DIN), U1.32 (P5_5)
unnamed: F1.A (1), K4.+
unnamed: D1.A, F1.K (2)
unnamed: C3.1, U1.39 (VCCD)
unnamed: K5.TX_RS232, P1.2, P2.2, P3.2
unnamed: C5.1, U1.63 (VCCA)
unnamed: K6.1, U1.42 (P15_0_MXTLO)
unnamed: C17.2, IC3.2 (CMP)
unnamed: C8.2, U1.86 (VCCD)
unnamed: C17.1, R6.2
unnamed: B1.+, B1.+@1 (+), P4.1
unnamed: C19.1, IC3.3 (FB), R11.2, R14.2, R26.2
unnamed: K7.1, U1.43 (P15_1_MXTLI)
unnamed: IC3.6 (GATE), T6.1 (G)
unnamed: R38.1, R50.2, R62.2, R75.2, T6.2 (S)
unnamed: K8.1, U1.44 (P3_0)
unnamed: C18.2, IC3.1 (ILIM), R38.2
unnamed: IC3.7 (TIM), R76.2
unnamed: D3.A, L1.P$1 (1), T6.3 (D)
unnamed: IC1.16 (VBAT), P4.2
RX: K5.RX_RS232, U1.31 (P5_4)
SCLK: IC1.18 (SCLK1), U1.35 (P15_6_DP)
SDIO: K3.5, U1.20 (P1_0_TMS_SWDIO)
TL1: S1.2 (S), U1.29 (P12_6)
TL2: S2.2 (S), U1.28 (P1_7)
TL3: S3.2 (S), U1.27 (P1_6)
TX: P1.1, U1.30 (P12_7)
U_ANODEP: C20.1, D3.K, K2.59, R26.1
XRES: K3.3, U1.15 (!XRES!)

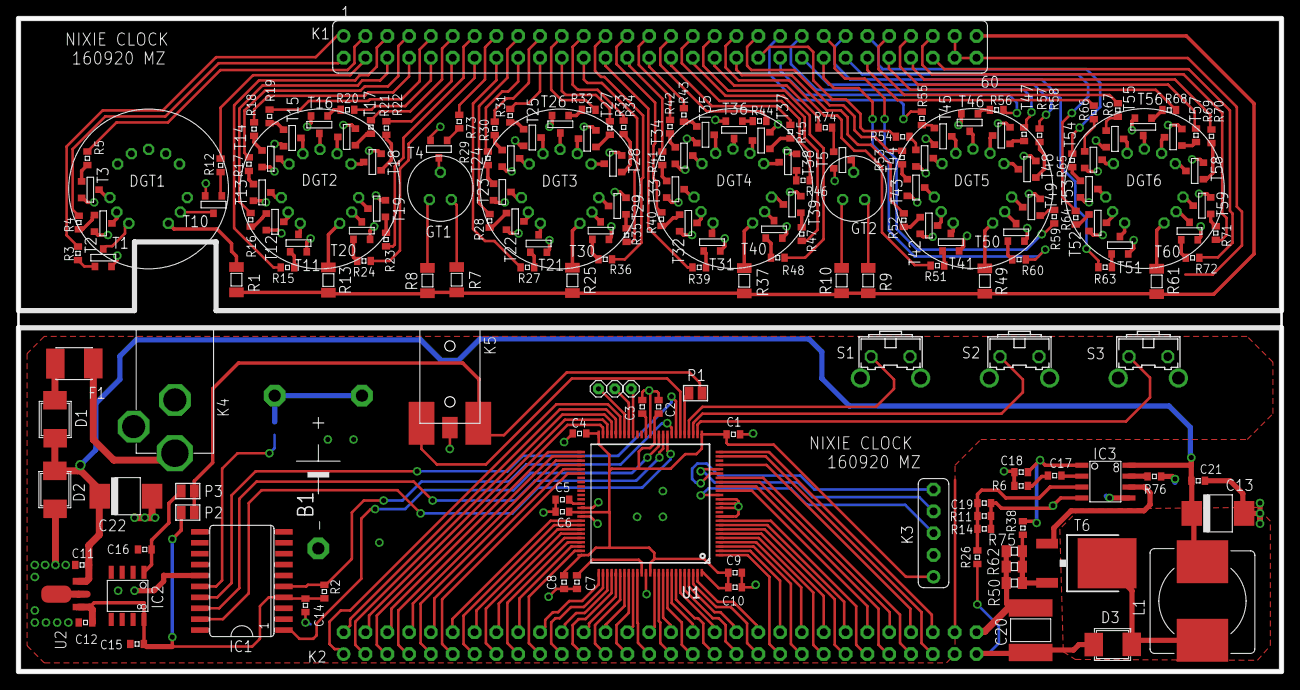
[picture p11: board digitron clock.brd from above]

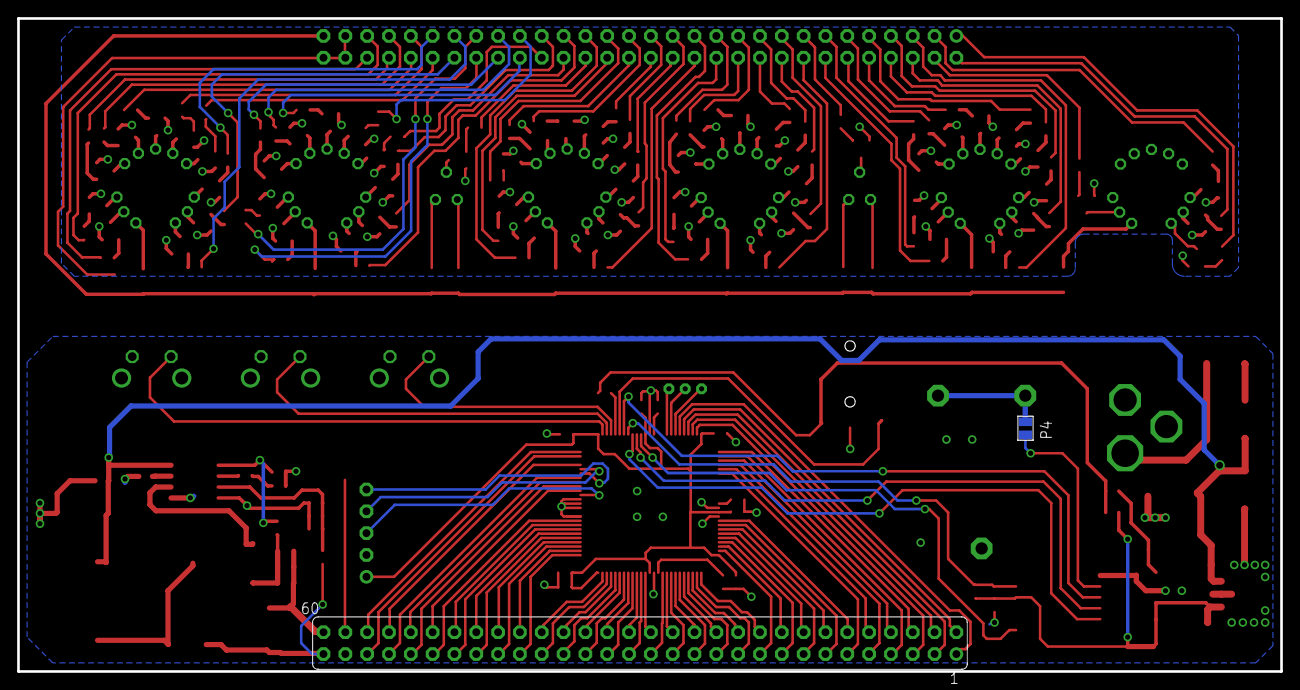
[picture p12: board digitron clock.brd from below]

Board: 2 copper layers, 147.0 x 76.0 mm, 189 parts (2 on the bottom side), 274 nets.

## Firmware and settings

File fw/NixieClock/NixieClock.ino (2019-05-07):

/*
Nixie Clock
*/
// Date and time functions using a DS3231 RTC connected via I2C and Wire lib
#include <Wire.h>
#include "RTClib.h"

RTC_DS3231 rtc;

int secondBefore = 0;

int digit1[]={A10,A11,A12,A13,A14,A15,52,53,50,51};
int digit2[]={A0,A1,A2,A3,A4,A5,A6,A7,A8,A9};
int digit3[]={48,49,46,47,44,45,42,43,40,41};
int digit4[]={38,39,36,37,34,35,32,33,30,31};
int digit5[]={28,29,26,27,24,25,22,23,15,14};
int digit6[]={10,9,8,7,6,5,4,3,2,0};


void setup() {  
  //Serial.begin(115200);      
  
  if (! rtc.begin()) {
    Serial.println("Couldn't find RTC");
    while (1);
  }
  
  //rtc.adjust(DateTime(2019, 4, 18, 12, 01, 00));
  rtc.adjust(DateTime(F(__DATE__), F(__TIME__)));    
  
  if (rtc.lostPower()) {
    Serial.println("RTC lost power, lets set the time!");
    // following line sets the RTC to the date & time this sketch was compiled
    rtc.adjust(DateTime(F(__DATE__), F(__TIME__)));    
    
    // This line sets the RTC with an explicit date & time, for example to set
    // January 21, 2014 at 3am you would call:
     //rtc.adjust(DateTime(2019, 4, 18, 10, 19, 00));
  }

  for (int i=0;i<=9;i++) {    
    pinMode(digit1[i], OUTPUT);  
    pinMode(digit2[i], OUTPUT);  
    pinMode(digit3[i], OUTPUT);  
    pinMode(digit4[i], OUTPUT);  
    pinMode(digit5[i], OUTPUT);  
    pinMode(digit6[i], OUTPUT);  

    digitalWrite(digit1[i], LOW);
    digitalWrite(digit2[i], LOW);
    digitalWrite(digit3[i], LOW);
    digitalWrite(digit4[i], LOW);
    digitalWrite(digit5[i], LOW);
    digitalWrite(digit6[i], LOW);    
  }
  
}

void loop() {
  //Read time from RTC
  DateTime now = rtc.now();            

    /* //UART debug
    Serial.print(now.hour(), DEC);
    Serial.print(':');
    Serial.print(now.minute(), DEC);
    Serial.print(':');
    Serial.print(now.second(), DEC);
    Serial.println();        
    */
    
    //Shutdown during night
    if (now.hour()<7) {
        for (int i=0;i<=9;i++) {    
          digitalWrite(digit1[i], LOW);
          digitalWrite(digit2[i], LOW);
          digitalWrite(digit3[i], LOW);
          digitalWrite(digit4[i], LOW);
          digitalWrite(digit5[i], LOW);
          digitalWrite(digit6[i], LOW);    
        } 
        delay(60000);
    }
    
    else {
      //Set actual time
      if (now.second()!= secondBefore) {
        secondBefore = now.second();
  
        for (int i=0;i<=9;i++) {
          digitalWrite(digit1[i], LOW);
          digitalWrite(digit2[i], LOW);
          digitalWrite(digit3[i], LOW);
          digitalWrite(digit4[i], LOW);
          digitalWrite(digit5[i], LOW);
          digitalWrite(digit6[i], LOW);
        }  
      
        digitalWrite(digit1[now.second()%10], HIGH);   
        digitalWrite(digit2[now.second()/10], HIGH);   
    
        digitalWrite(digit3[now.minute()%10], HIGH);   
        digitalWrite(digit4[now.minute()/10], HIGH);   
    
        digitalWrite(digit5[now.hour()%10], HIGH);   
        digitalWrite(digit6[now.hour()/10], HIGH);     
      }

      //Cycling numbers once per minute to prevent cathode poisoning
      if (now.second()==45) {
          for (int i=0;i<=9;i++) {             
            digitalWrite(digit1[i], LOW);
            digitalWrite(digit2[i], LOW);
            digitalWrite(digit3[i], LOW);
            digitalWrite(digit4[i], LOW);
            digitalWrite(digit5[i], LOW);
            digitalWrite(digit6[i], LOW);    
          } 
    
        for (int i=0;i<=9;i++) {    
          digitalWrite(digit1[i], HIGH);   
          digitalWrite(digit2[i], HIGH);   
          digitalWrite(digit3[i], HIGH);   
          digitalWrite(digit4[i], HIGH);   
          digitalWrite(digit5[i], HIGH);   
          digitalWrite(digit6[i], HIGH);   
          delay(300);                       
          
          digitalWrite(digit1[i], LOW);
          digitalWrite(digit2[i], LOW);
          digitalWrite(digit3[i], LOW);
          digitalWrite(digit4[i], LOW);
          digitalWrite(digit5[i], LOW);
          digitalWrite(digit6[i], LOW);
        }  
      }  
    }
    
    delay(100);
    
  
  
}

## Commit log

2019-03-14 Final v1.0
    [NixieClock01A-B.Cu.gbr, NixieClock01A-B.Mask.gbr, NixieClock01A-B.Paste.gbr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]
2019-03-19 BJT transistors test. added Arduino Mega dimensions
    [MEGA2560_Rev3e-Dwgs.User.dxf, MEGA2560_Rev3e-F.SilkS.dxf, MEGA2560_Rev3e.brd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]
2019-03-19 Added Arduino Mega dimensions, Added DS3231
    [NixieClock01A.sch]
2019-03-20 Added pin headers for Arduino Mega. Added first two nixies, Changed PCB dimensions
    [NixieClock01A.sch, nixies.sch]
2019-03-20 Added all nixies, added DC-DC converter, basic routing done
    [NixieClock01A.sch, nixies.sch]
2019-03-21 Added RTC, ERC done, DRC done, Silk layer revision
    [MEGA2560_Rev3e-Dwgs.User.dxf, MEGA2560_Rev3e-F.SilkS.dxf, MEGA2560_Rev3e.brd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]
2019-03-22 Added KiCAD lib files
2019-03-22 Deleted old gerber files
    [NixieClock01A-B.Cu.gbr, NixieClock01A-B.Mask.gbr, NixieClock01A-B.Paste.gbr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]
2019-03-22 Added buttons
    [NixieClock01A.sch, nixies.sch]
2019-03-22 PCB manufactured
    [NixieClock01A-B.Cu.gbr, NixieClock01A-B.Mask.gbr, NixieClock01A-B.Paste.gbr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]
2019-04-17 GPIOs correction, Added RTC reading (first test)
    [NixieClock.ino]
2019-04-18 First version of working firmware. Small components values change
    [NixieClock01A.sch, nixies.sch]
2019-04-18 Changed BJT base resistor values, Added photo, Added new inspiration schematic, Changed README
    [MEGA2560_Rev3e-Dwgs.User.dxf, MEGA2560_Rev3e-F.SilkS.dxf, NixieClock01A.sch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]
2019-04-23 Solved I2C, UART conflict
    [NixieClock01A.sch, nixies.sch]
